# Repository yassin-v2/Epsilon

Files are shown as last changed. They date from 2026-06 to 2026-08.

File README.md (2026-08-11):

# Epsilon

A very compact, 4-layer devboard integrating the RP2354A MCU, named Epsilon.

---

<p align="center">
  
</p>

<p align="center">
  
</p>

---

## Features

- **RP2354A MCU** - 32bit dual core ARM Cortex-M33 MCU, with RISC-V cores and 2Mb of internal flash memory.
- **Very compact, XIAO SEEED inspired formfactor**.
- **4 ADC and 7 digital GPIO pins**.
- **5V and 3.3V output power pins**.
- Power indicator LED and addressable LED.
- **USB C** - for programming and power.

---

## PCB Design

*Find the PCB files [here](https://github.com/yassin-v2/Epsilon/tree/main/PCB).*

The PCB is 4 layers with dimensions **21mm × 17.8mm**.

| Top Layer | Inner Plane 1; GND |
|:---:|:---:|
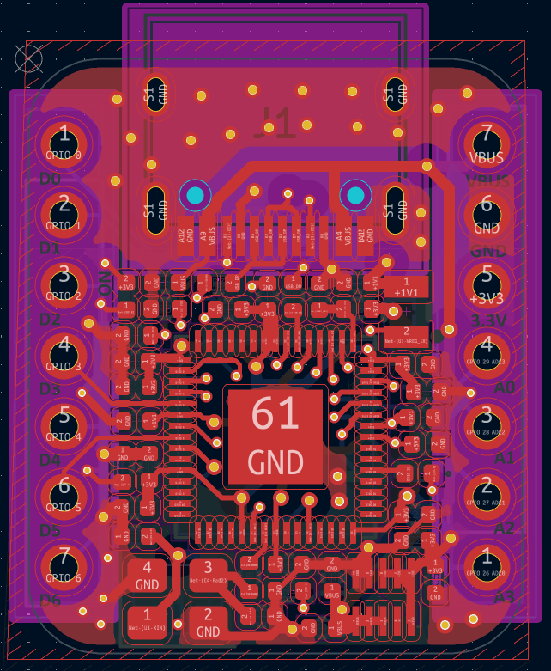
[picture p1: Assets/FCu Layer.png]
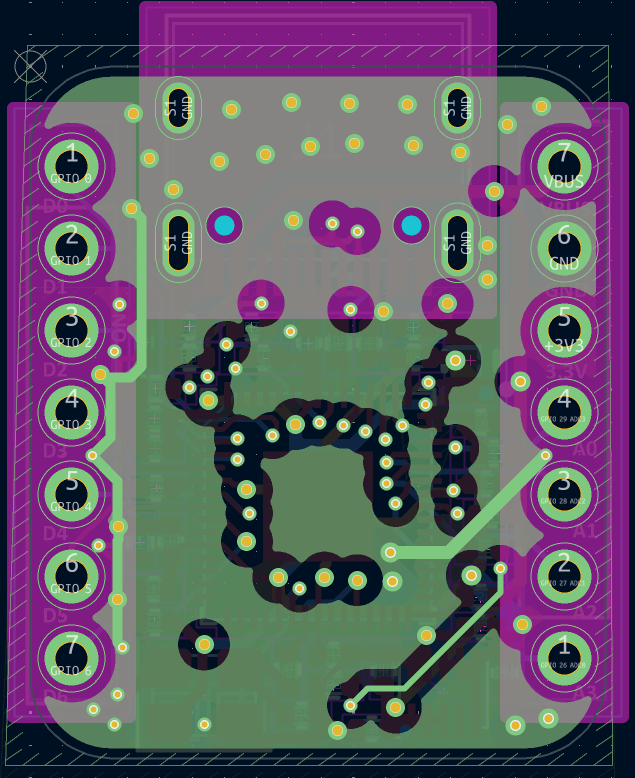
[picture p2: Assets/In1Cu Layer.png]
|  |  |

| Inner Plane 2; Power | Bottom Layer |
|:---:|:---:|
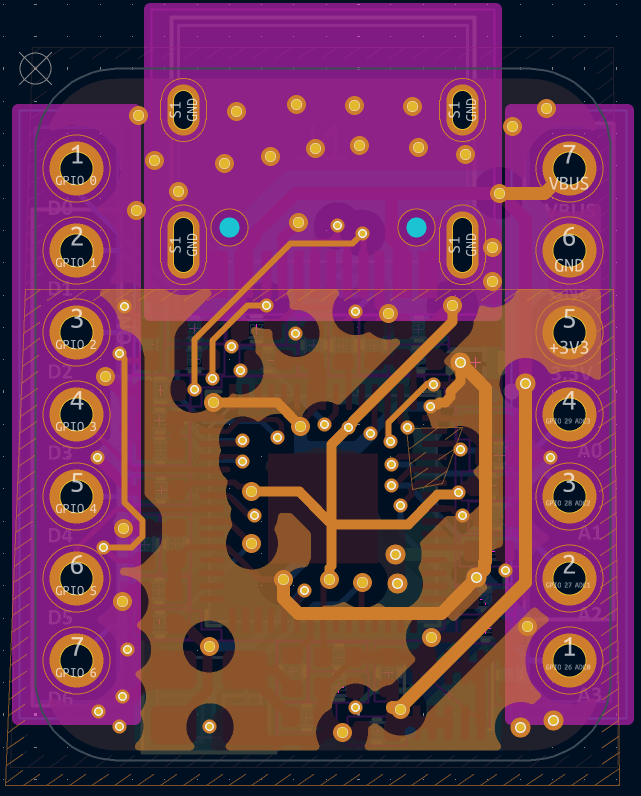
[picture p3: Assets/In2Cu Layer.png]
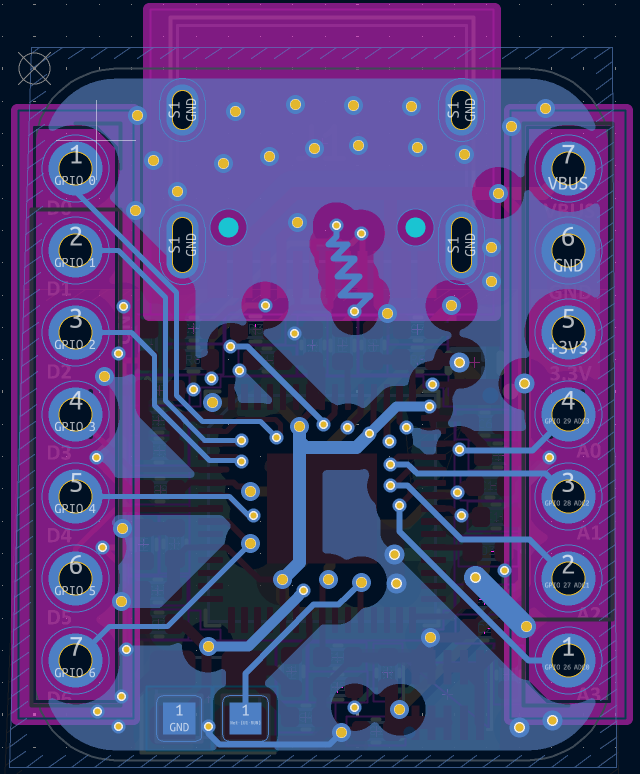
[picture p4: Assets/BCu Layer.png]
|  |  |

---

## Schematic Design

*Find the Schematic files [here](https://github.com/yassin-v2/Epsilon/tree/main/PCB), or as a PDF, [here](https://github.com/yassin-v2/Epsilon/blob/main/Epsilon%20Schematic.pdf).*

<p align="center">
  
</p>

---

## Pinout

<p align="center">
  
</p>

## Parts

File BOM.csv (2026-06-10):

Item | Price (USD)
PCB Manufacturing | 2.00
PCBA Parts Assembly | 36.21

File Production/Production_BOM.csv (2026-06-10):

Designator | Footprint | Quantity | Value | LCSC Part #
C1, C19, C2, C22, C5 | 0402 | 5 | 10uF
C10, C6, C7, C9 | 0402 | 4 | 4.7uF
C11, C12, C13, C14, C15, C16, C17, C18, C20, C21, C8 | 0402 | 11 | 100nF
C3, C4 | 0402 | 2 | 15pF
D2, D3 | 0402 | 2 | LED
J1 | USB_C_Receptacle_HRO_TYPE-C-31-M-12 | 1 | USB_C_Receptacle_USB2.0_16P
L1 | IND-SMD_L2.0-W1.6_AOTA-B201610S3R3-101-T | 1 | 3.3uH | C42411119
R1 | 0402 | 1 | 1k
R2, R3, R6 | 0402 | 3 | 33
R4, R5 | 0402 | 2 | 470
R7, R8 | 0402 | 2 | 5.1K
U1 | QFN-60-1EP_7x7mm_P0.4mm_EP3.4x3.4mm | 1 | RP2354A
U2 | USIP-10_L2.5-W2.0-P0.50-BL | 1 | TPSM828214SILR | C2876792
Y1 | Crystal_SMD_Abracon_ABM8G-4Pin_3.2x2.5mm | 1 | 12MHz

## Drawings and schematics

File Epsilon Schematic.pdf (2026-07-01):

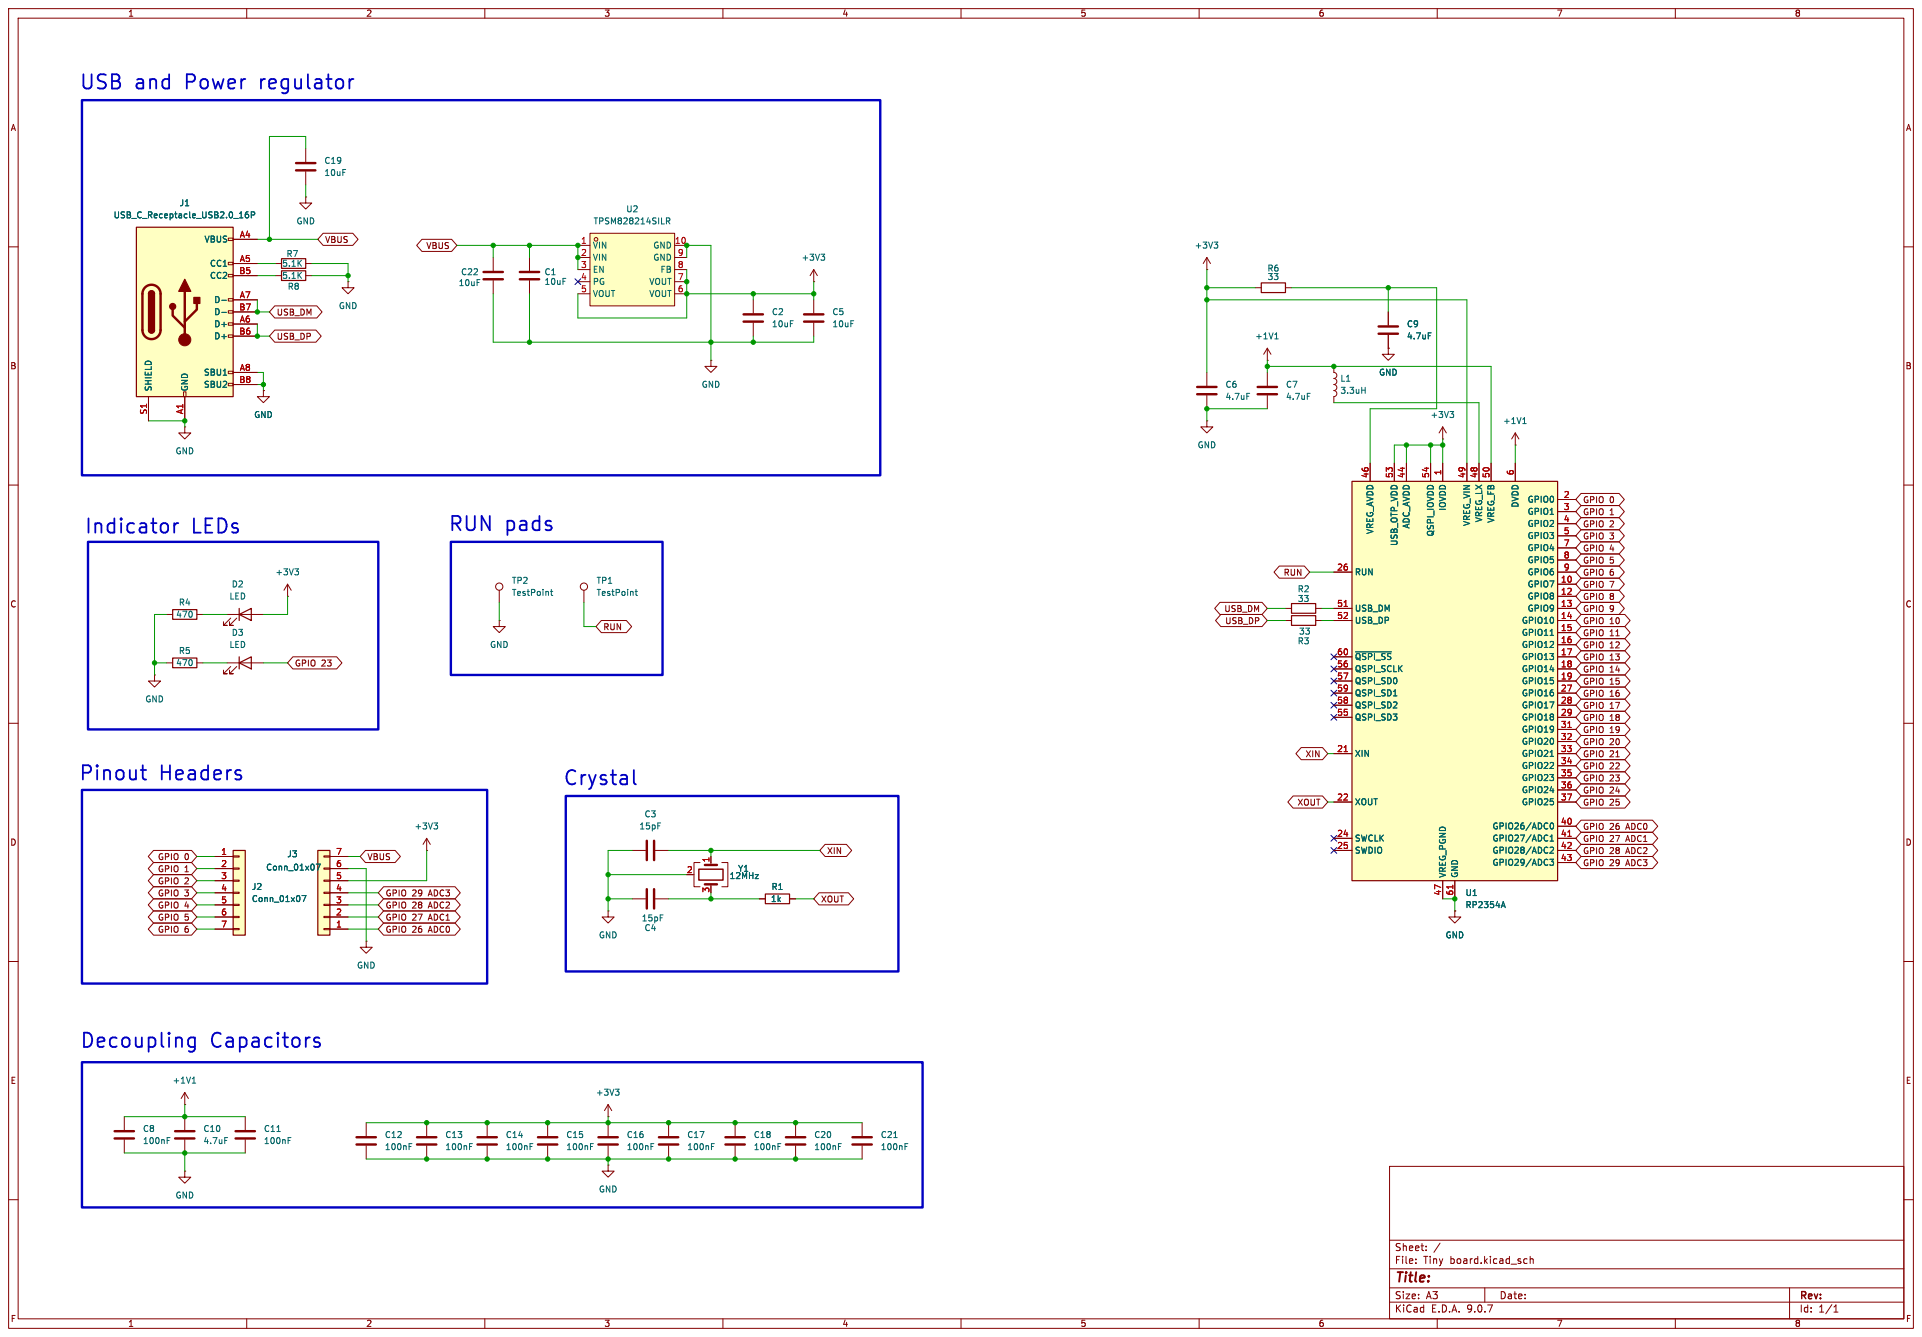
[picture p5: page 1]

USB and Power regulator

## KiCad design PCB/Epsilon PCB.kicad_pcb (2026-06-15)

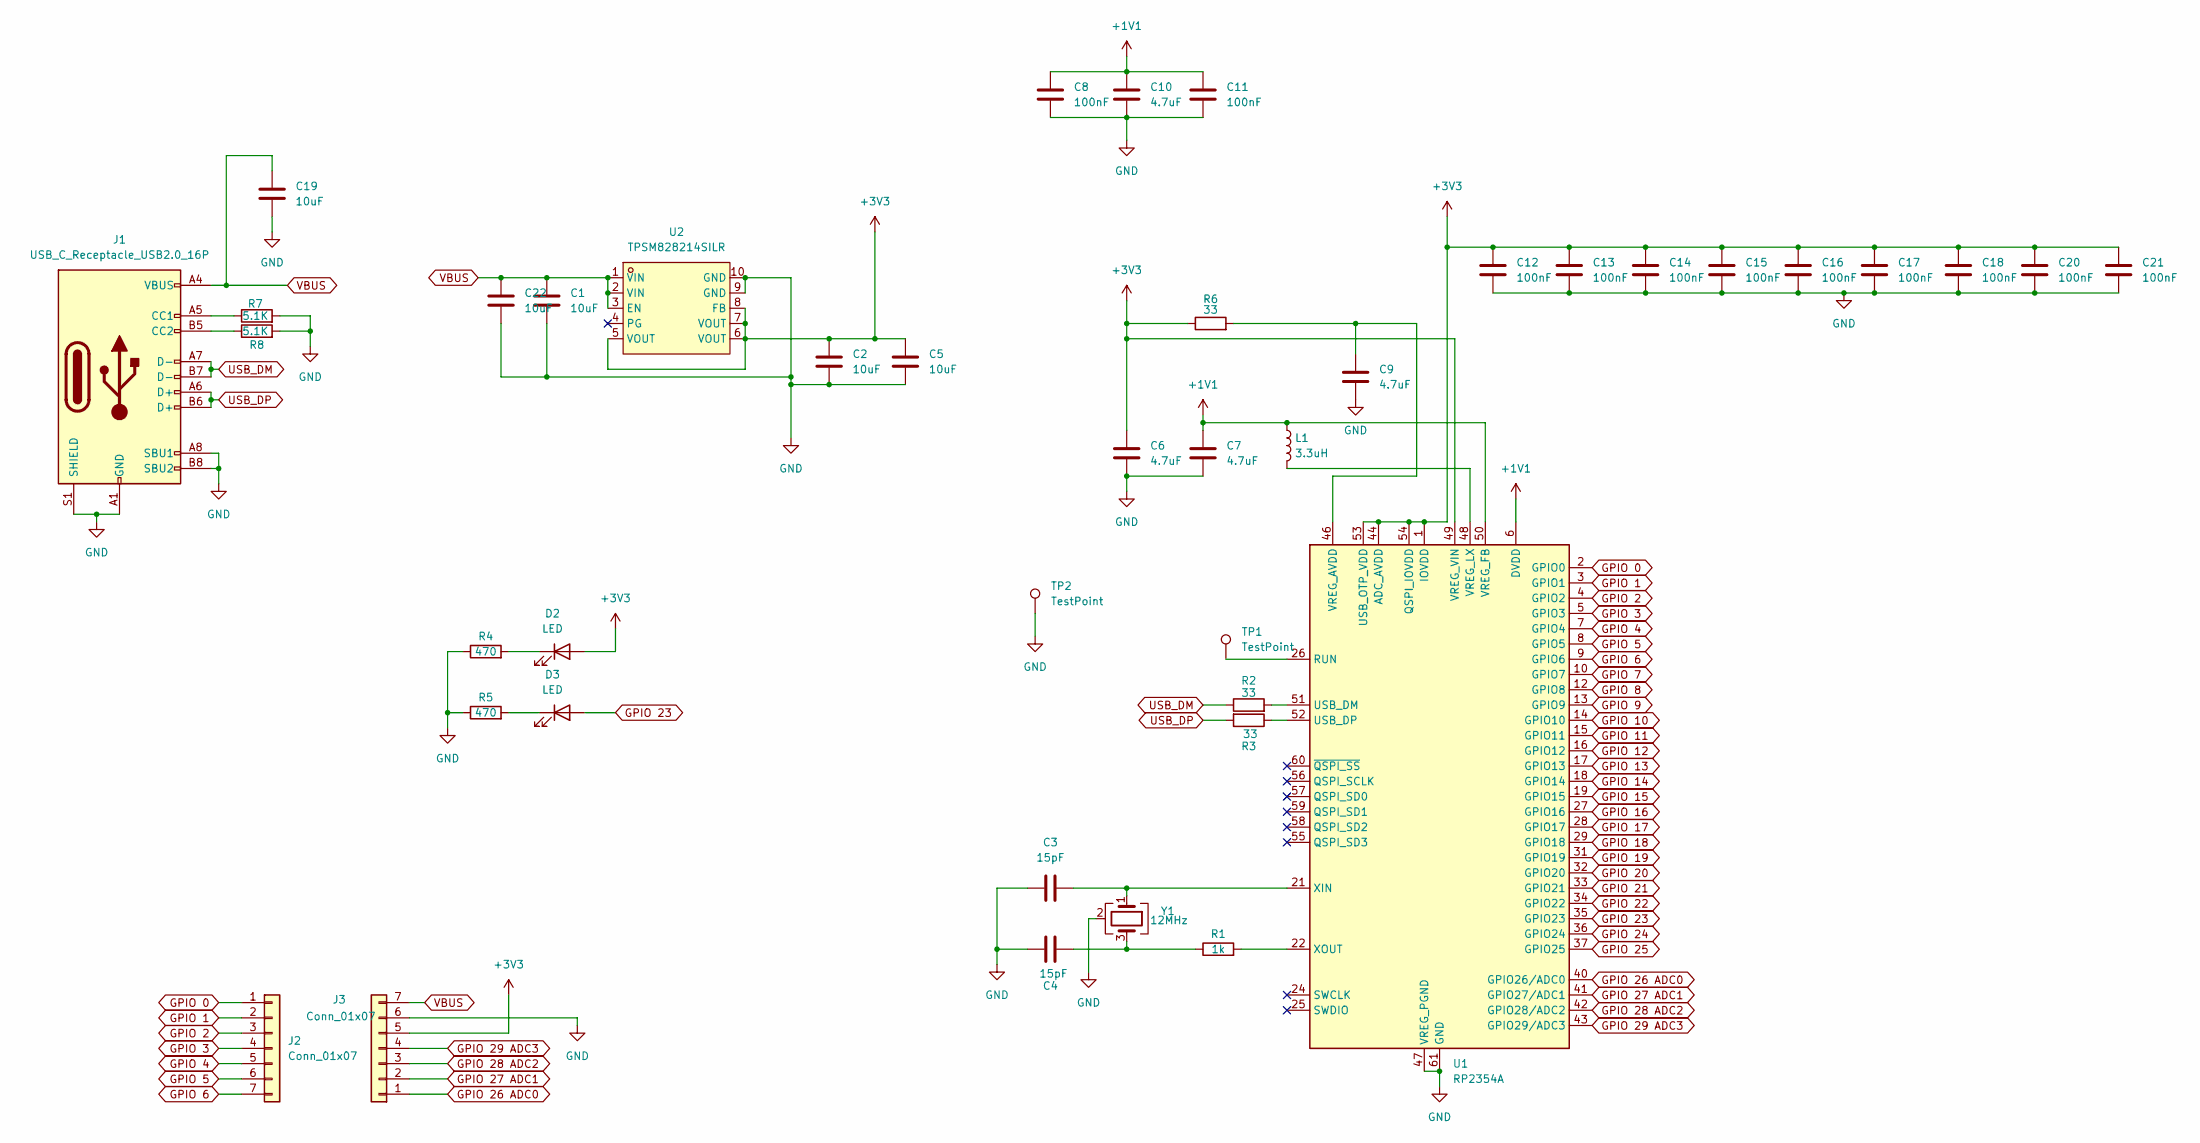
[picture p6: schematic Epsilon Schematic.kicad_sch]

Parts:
C1, C2, C5, C19, C22: 10uF; C_0402_1005Metric
C3, C4: 15pF; C_0402_1005Metric
C6, C7, C9, C10: 4.7uF; C_0402_1005Metric
C8, C11, C12, C13, C14, C15, C16, C17, C18, C20, C21: 100nF; C_0402_1005Metric
D2, D3: LED; LED_0402_1005Metric
J1: USB_C_Receptacle_USB2.0_16P; USB_C_Receptacle_HRO_TYPE-C-31-M-12
J2, J3: Conn_01x07; PinHeader_1x07_P2.54mm_Vertical
L1: 3.3uH; IND-SMD_L2.0-W1.6_AOTA-B201610S3R3-101-T
R1: 1k; R_0402_1005Metric
R2, R3, R6: 33; R_0402_1005Metric
R4, R5: 470; R_0402_1005Metric
R7, R8: 5.1K; R_0402_1005Metric
TP1, TP2: TestPoint; TestPoint_Pad_1.0x1.0mm
U1: RP2354A; QFN-60-1EP_7x7mm_P0.4mm_EP3.4x3.4mm
U2: TPSM828214SILR; USIP-10_L2.5-W2.0-P0.50-BL; MPN TPSM828214SILR; LCSC Part C2876792
Y1: 12MHz; Crystal_SMD_Abracon_ABM8G-4Pin_3.2x2.5mm

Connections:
+1V1: C7.1, C8.1, C10.1, C11.1, L1.1, U1.6 (DVDD), U1.23 (DVDD), U1.39 (DVDD), U1.50 (VREG_FB)
+3V3: C2.1, C5.1, C6.1, C12.1, C13.1, C14.1, C15.1, C16.1, C17.1, C18.1, C20.1, C21.1, D2.2 (A), J3.5, R6.1, U1.1 (IOVDD), U1.11 (IOVDD), U1.20 (IOVDD), U1.30 (IOVDD), U1.38 (IOVDD), U1.44 (ADC_AVDD), U1.45 (IOVDD), U1.49 (VREG_VIN), U1.53 (USB_OTP_VDD), U1.54 (QSPI_IOVDD), U2.5 (VOUT), U2.6 (VOUT), U2.7 (VOUT), U2.8 (FB)
GND: C1.2, C2.2, C3.1, C4.1, C5.2, C6.2, C7.2, C8.2, C9.2, C10.2, C11.2, C12.2, C13.2, C14.2, C15.2, C16.2, C17.2, C18.2, C19.2, C20.2, C21.2, C22.2, J1.A1 (GND), J1.A8 (SBU1), J1.A12 (GND), J1.B1 (GND), J1.B8 (SBU2), J1.B12 (GND), J1.S1 (SHIELD), J3.6, R4.1, R5.1, R7.2, R8.2, TP2.1, U1.47 (VREG_PGND), U1.61 (GND), U2.9 (GND), U2.10 (GND), Y1.2 (G), Y1.4 (G)
GPIO 0: J2.1, U1.2 (GPIO0)
GPIO 1: J2.2, U1.3 (GPIO1)
GPIO 2: J2.3, U1.4 (GPIO2)
GPIO 3: J2.4, U1.5 (GPIO3)
GPIO 4: J2.5, U1.7 (GPIO4)
GPIO 5: J2.6, U1.8 (GPIO5)
GPIO 6: J2.7, U1.9 (GPIO6)
GPIO 7: U1.10 (GPIO7)
GPIO 8: U1.12 (GPIO8)
GPIO 9: U1.13 (GPIO9)
GPIO 10: U1.14 (GPIO10)
GPIO 11: U1.15 (GPIO11)
GPIO 12: U1.16 (GPIO12)
GPIO 13: U1.17 (GPIO13)
GPIO 14: U1.18 (GPIO14)
GPIO 15: U1.19 (GPIO15)
GPIO 16: U1.27 (GPIO16)
GPIO 17: U1.28 (GPIO17)
GPIO 18: U1.29 (GPIO18)
GPIO 19: U1.31 (GPIO19)
GPIO 20: U1.32 (GPIO20)
GPIO 21: U1.33 (GPIO21)
GPIO 22: U1.34 (GPIO22)
GPIO 23: D3.2 (A), U1.35 (GPIO23)
GPIO 24: U1.36 (GPIO24)
GPIO 25: U1.37 (GPIO25)
GPIO 26 ADC0: J3.1, U1.40 (GPIO26/ADC0)
GPIO 27 ADC1: J3.2, U1.41 (GPIO27/ADC1)
GPIO 28 ADC2: J3.3, U1.42 (GPIO28/ADC2)
GPIO 29 ADC3: J3.4, U1.43 (GPIO29/ADC3)
unnamed: C4.2, R1.1, Y1.3
unnamed: D2.1 (K), R4.2
unnamed: D3.1 (K), R5.2
unnamed: J1.A5 (CC1), R7.1
unnamed: J1.B5 (CC2), R8.1
unnamed: TP1.1, U1.26 (RUN)
unnamed: R2.2, U1.51 (USB_DM)
unnamed: R3.1, U1.52 (USB_DP)
unnamed: C9.1, R6.2, U1.46 (VREG_AVDD)
unnamed: L1.2, U1.48 (VREG_LX)
unnamed: C3.2, U1.21 (XIN), Y1.1
unnamed: R1.2, U1.22 (XOUT)
USB_DM: J1.A7 (D-), J1.B7 (D-), R2.1
USB_DP: J1.A6 (D+), J1.B6 (D+), R3.2
VBUS: C1.1, C19.1, C22.1, J1.A4 (VBUS), J1.A9 (VBUS), J1.B4 (VBUS), J1.B9 (VBUS), J3.7, U2.1 (VIN), U2.2 (VIN), U2.3 (EN)

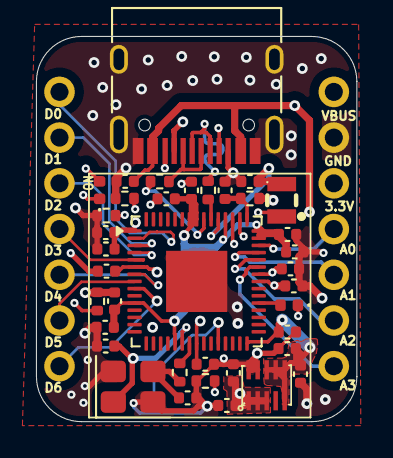
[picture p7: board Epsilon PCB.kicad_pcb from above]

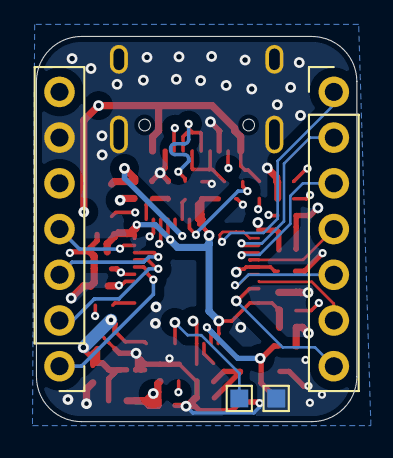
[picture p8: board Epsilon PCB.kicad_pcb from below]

Board: 4 copper layers, 17.8 x 21.4 mm, 41 parts (4 on the bottom side), 30 nets.

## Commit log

2026-06-10 Change BOM.csv to use comma-separated values
    [BOM.csv]
2026-06-15 Readded PCB file with pro file
    [Epsilon PCB.kicad_pcb, Epsilon Schematic.kicad_sch]
2026-07-01 Add PDF schematic
2026-08-11 Updated schematic image
